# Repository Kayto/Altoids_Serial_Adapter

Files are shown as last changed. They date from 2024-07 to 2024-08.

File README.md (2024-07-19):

# Altoids Serial Adapter

**Latest News**

* **DESIGN IN PROGRESS. UNTESTED**

## Introduction

Fed up with having to use multiple USB serial adapters and wiring configurations? Just want to plug in and go. This project was born from a desire for a quick and neat way to interface with various single board homebrew computers (SBCs)- such as the Kim-Uno, Southern Cross and SC131 to name a few. Most USB serial adapters are bare boards, have tiny pin labels and come with different logic voltages and pin out orders. This makes it a fiddle to set up. What power, what logic, mess around switching dupont jumper cables between the correct pins....
With the Altoid Serial Adapter the fiddle is over. You're welcome!

## Credits and thanks

Credits and thanks are worthy of being up front.

* **Lee Hart** for inspiring the look and feel of this project. Please check out his site for some amazing SBCs. https://www.sunrise-ev.com/index.htm
* Tom Van Baak for the brilliant picDIV™ project. Please check out his site for all things clock.
* bborncr for the initial PCB outline and sizing to fit the Altoids tin. https://github.com/bborncr/AltoidsPCB
* FTDI 

## General Aims

* Provide 'plug and play' connections using fixed ribbon cables for the most typical serial pin connection order. I don't want to be crossing wires and tracing wire colours.
* Provide some nice LEDs.
* Switchable power and serial logic voltages.
* Fit it all to look nice and tidy in an Altoids tin.
* For ease, safety and to simplify both design and assembly (and probably cost) use commercially available modules for the power regulation, multiplexing and charging.
* Limit the SMD to ease assembly.

## Bespoke Aims

These are added features that suit more bespoke applications.

* SBCs such as the Kim-Uno and Membership Cards dont always warrant a serial connection as they can be programmed by switches and buttons. Therefore why not provide some onboard battery power.
* With an onboard battery, may as well be able to charge it.
* As we have regulated power we may as well break it out - to be useful for other things.
* Sometimes you may need a signal High or Low? My use is that some SBCs need a High or Low to activate a display. Provide a switch for that, i like switches.
* Ok, the serial adapter IC has an onboard oscillator. It would be a shame to waste that. Wait, the oscillator runs at 2024 speeds, i need something slower for 1980s tech. Use a PIC to divide the clock and provide a breakout for sub 6MHZ clock signals. Might come in handy.
* For the clock, provide breakouts for onboard PIC programming. This then offers more possibilities without having to disassemble the board.

## Final Features

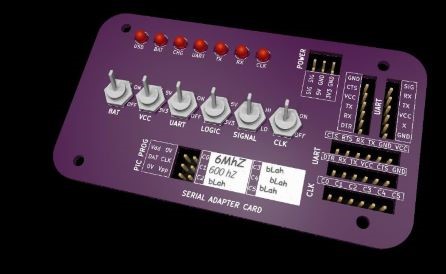
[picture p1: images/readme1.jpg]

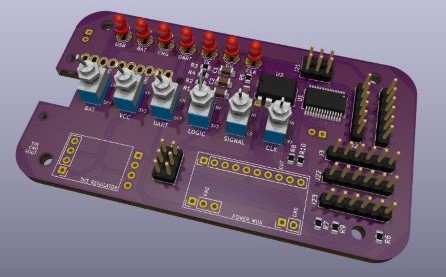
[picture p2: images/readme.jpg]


In no particular order the main features in the final board are as follows.

- Programmable clock breakout using the picDIV™ project.
- Indicator LEDs for the main functions and configurations.
- Onboard Li-ion battery charger.
- Selectable 5V and 3V3 power and logic.
- Seperate Power breakout.
- High and Low signal logic breakout

## Build

Coming Soon.

### REVISION STATUS & ISSUES
**REV 000**
* DRAFT DESIGN IN PRODUCTION. UNTESTED AT THE MOMENT.

## Firmware

Comming soon.
Instructions for the FT232R clock configuration.
Instructions for the picDIV™ project.

## Licenses & acknowledgement
Further to the links in the credit section.

**KiCad Library**

**picDIV™**
http://www.leapsecond.com/pic/
http://www.leapsecond.com/pic/src/readme

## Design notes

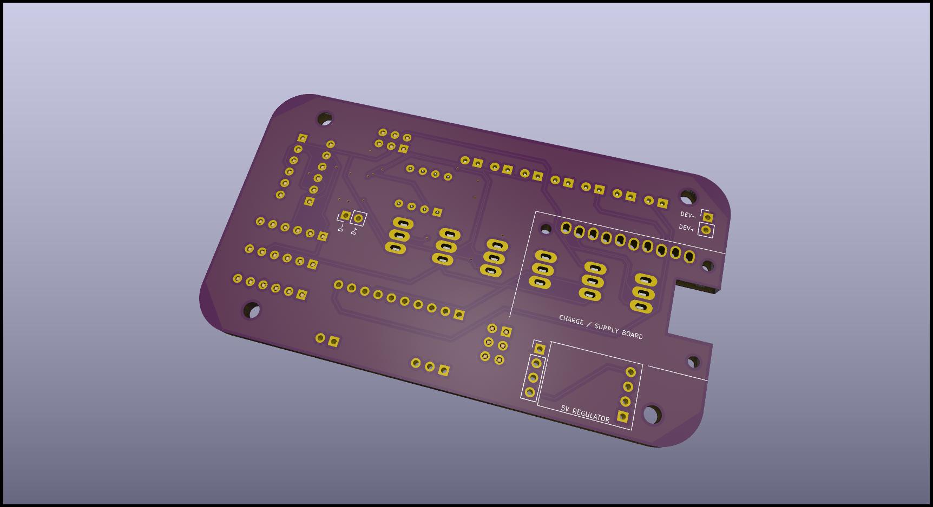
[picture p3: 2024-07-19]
images/Altoids_BOTTOM.jpg

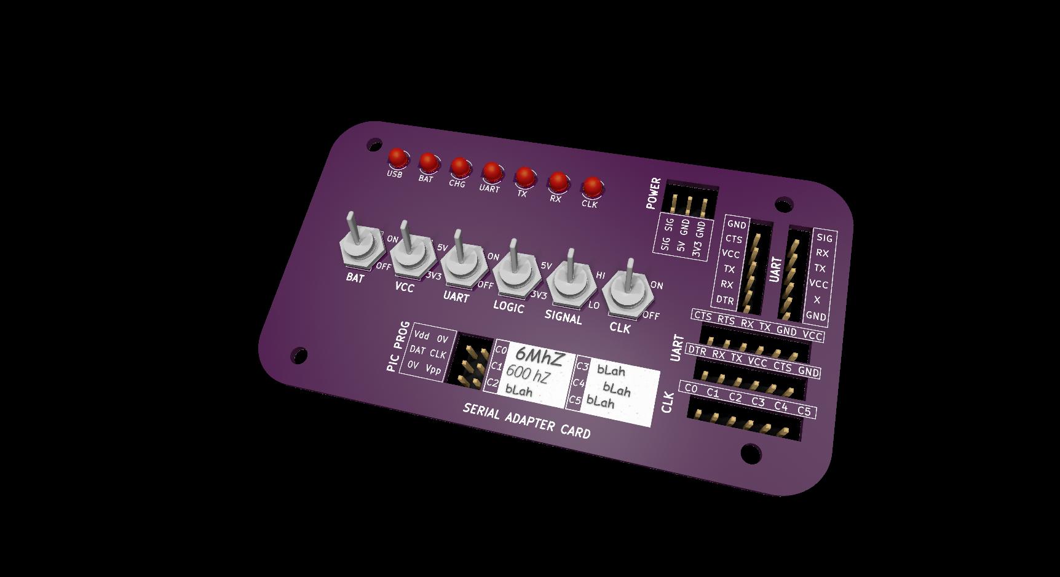
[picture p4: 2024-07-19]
images/Altoids_TOP.jpg

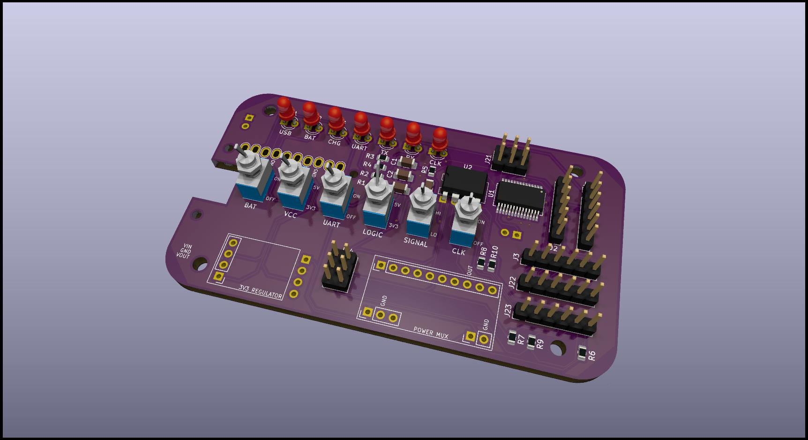
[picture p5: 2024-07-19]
images/Altoids.jpg

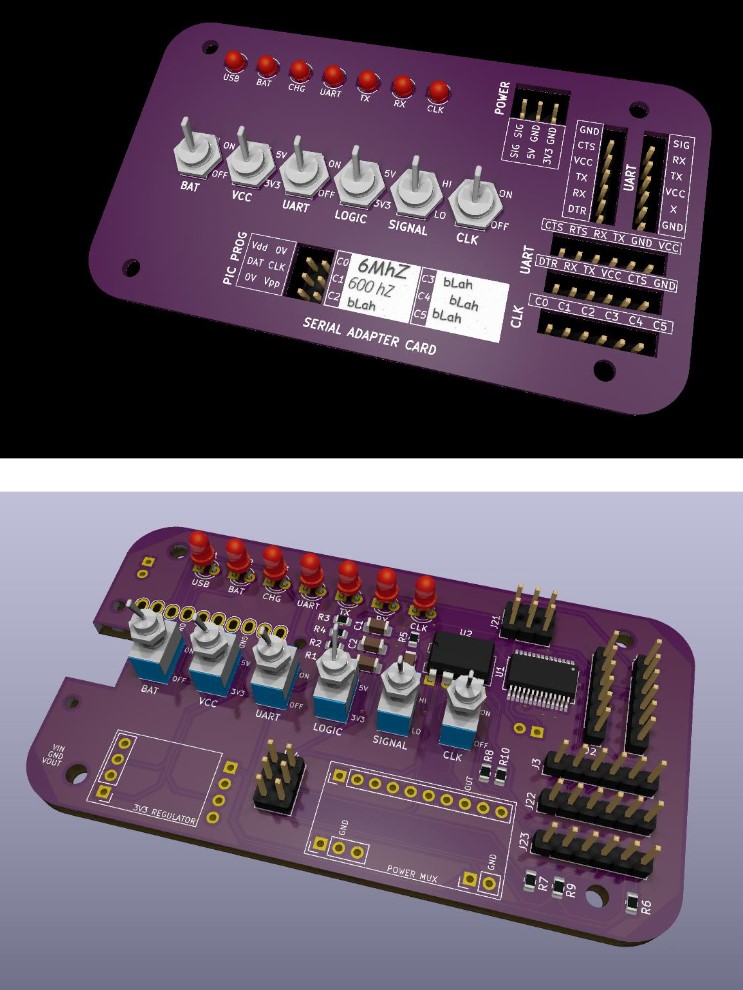
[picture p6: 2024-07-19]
images/readme - Copy.jpg

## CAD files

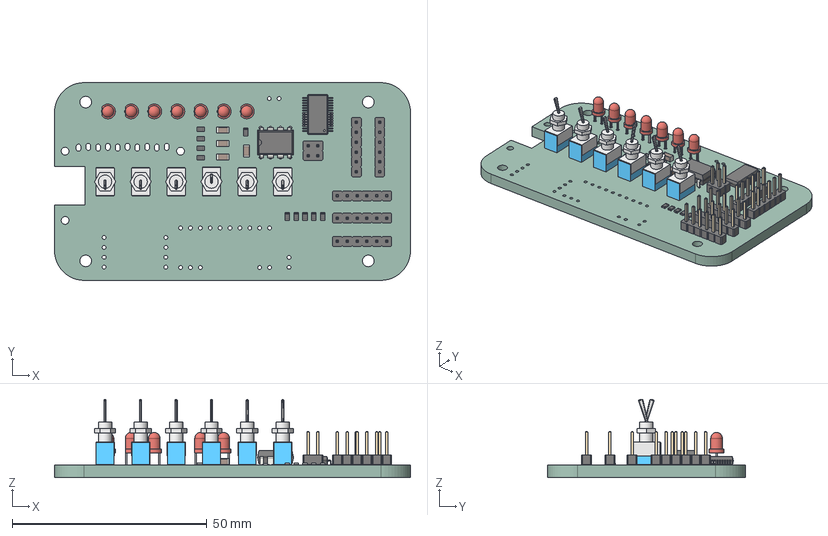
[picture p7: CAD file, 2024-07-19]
KiCAD/Altoids.step
91.4 x 50.8 x 20.1 mm
PinHeader_1x06_P254mm_Vertical x 5
R_0805_2012Metric x 10
C_1206_3216Metric x 4
DIP-8_W7.62mm
LED_D3.0mm x 7
PinHeader_2x02_P254mm_Vertical
SSOP_28_53x102mm_P065mm
_autosave-Altoids_PCB

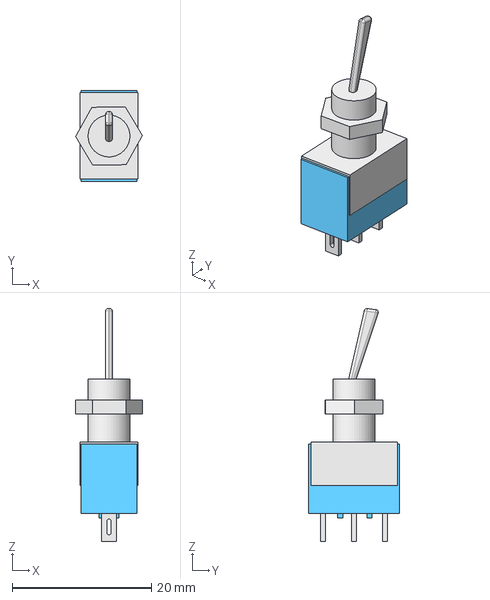
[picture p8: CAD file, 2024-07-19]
KiCAD/Toggle_SW_Blue_R0.step
9.58 x 13.0 x 33.4 mm
Housing
Chrome

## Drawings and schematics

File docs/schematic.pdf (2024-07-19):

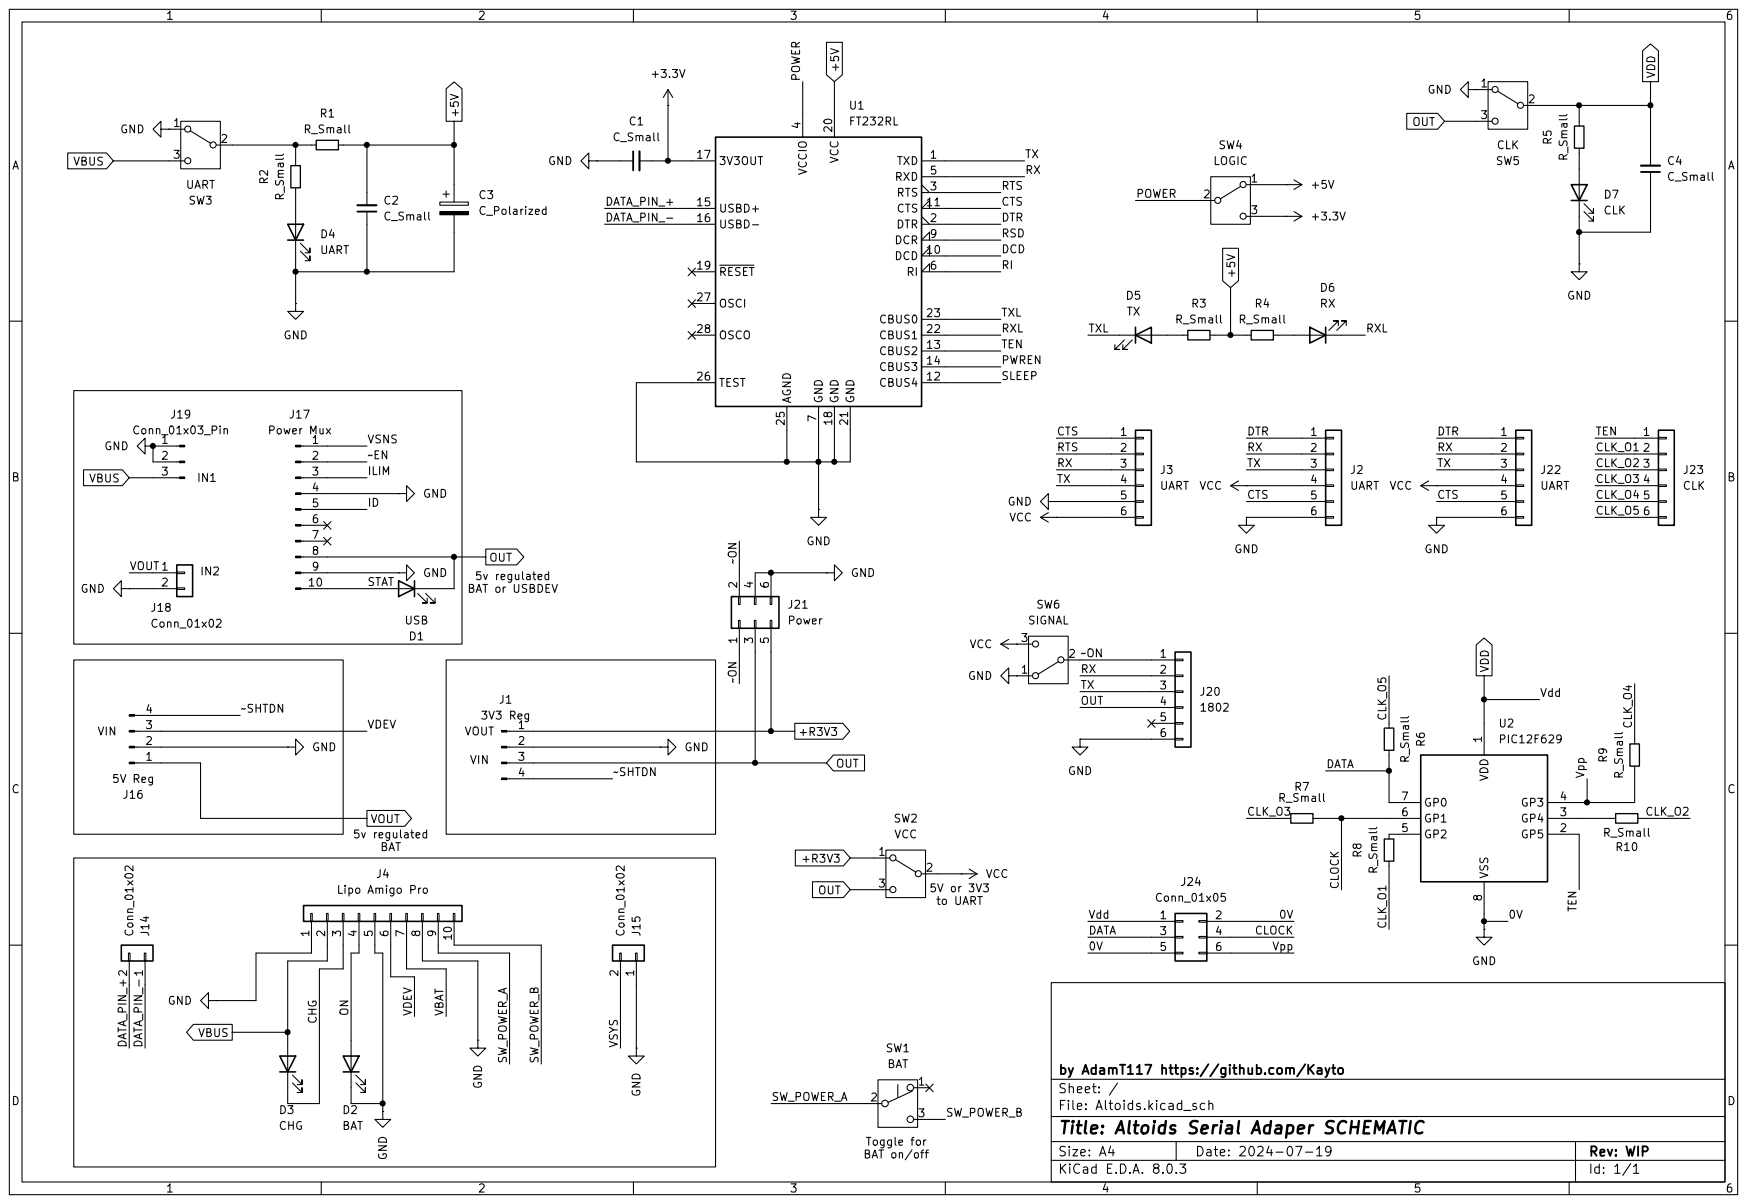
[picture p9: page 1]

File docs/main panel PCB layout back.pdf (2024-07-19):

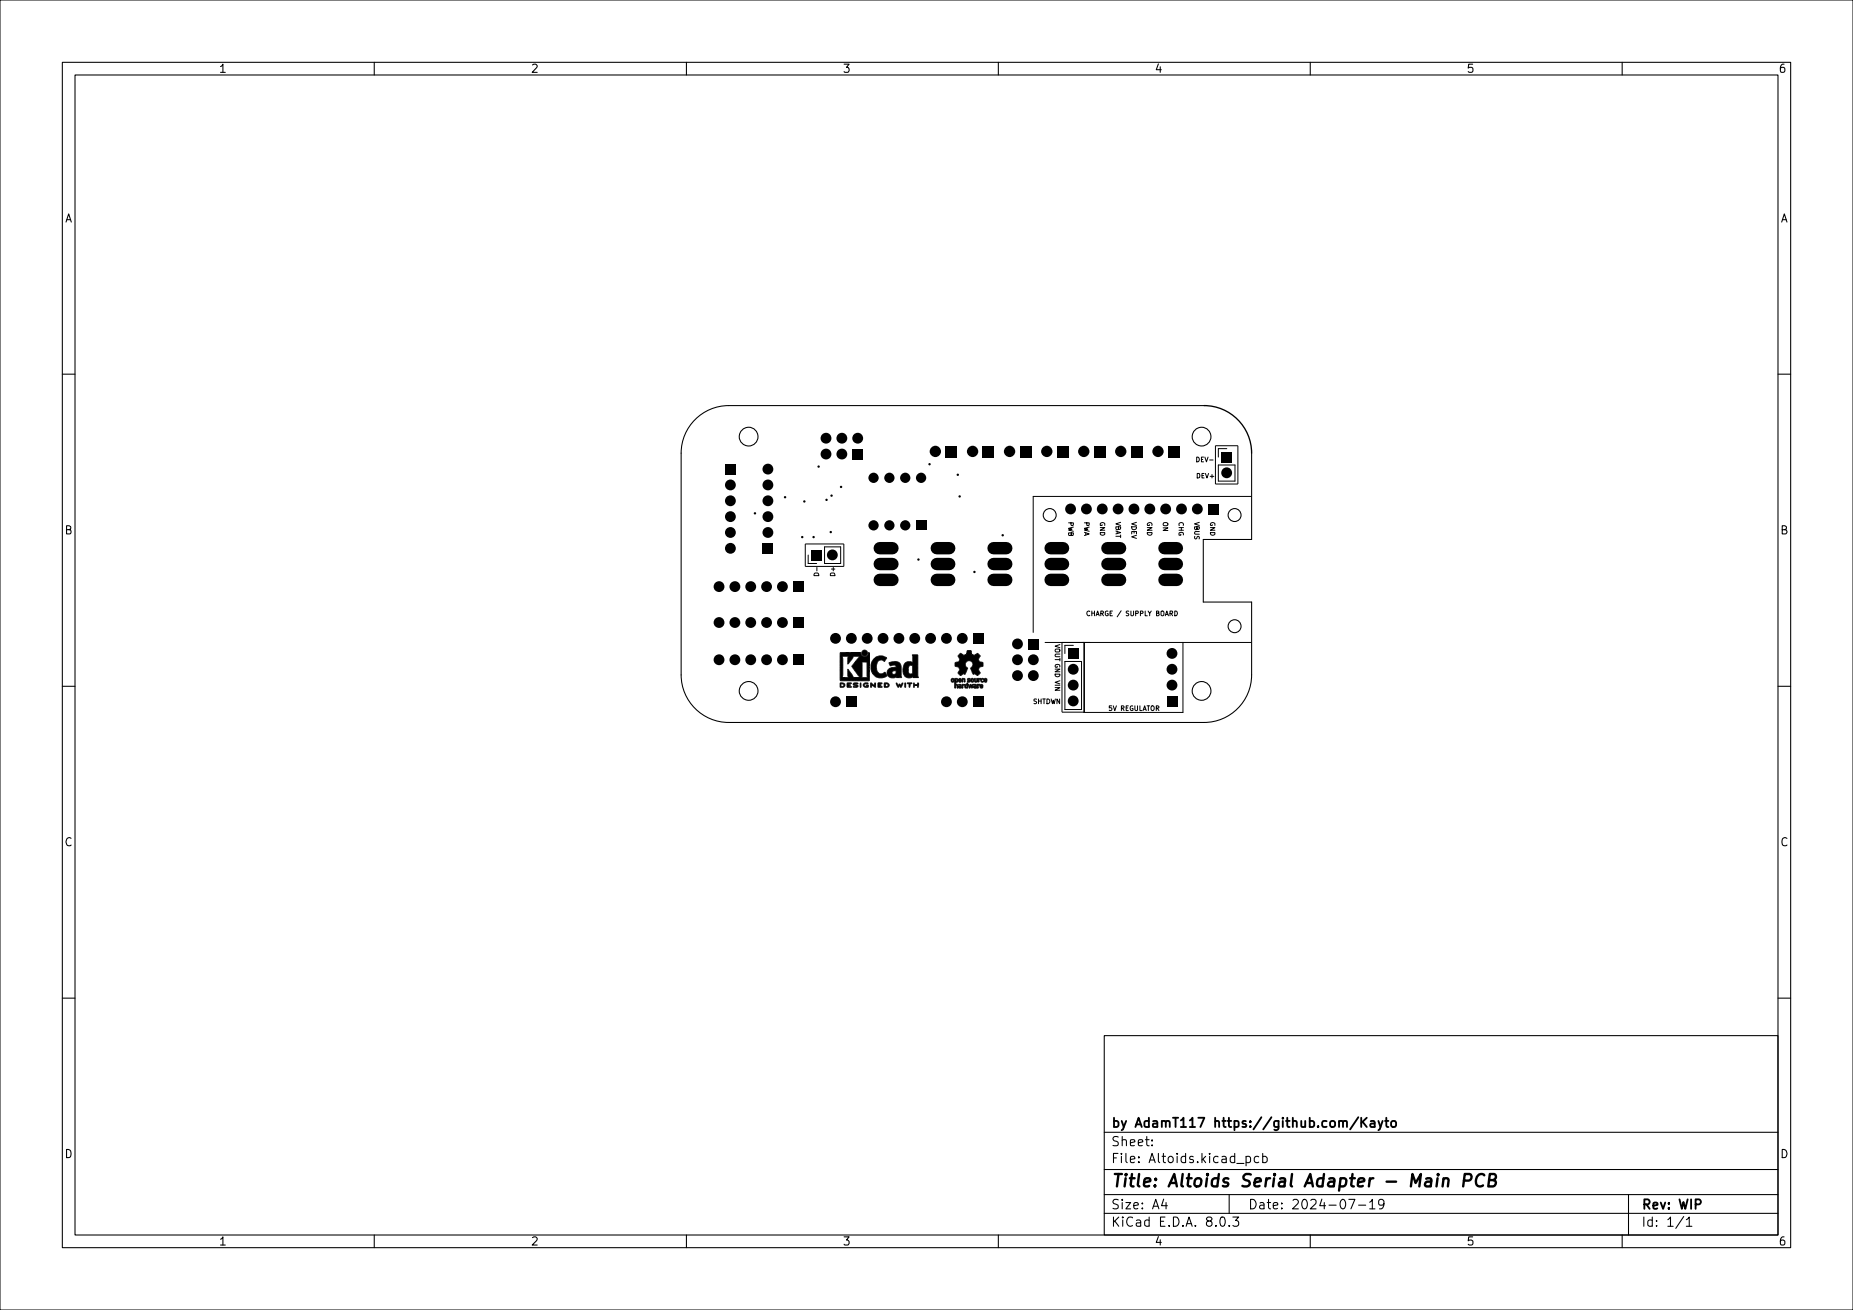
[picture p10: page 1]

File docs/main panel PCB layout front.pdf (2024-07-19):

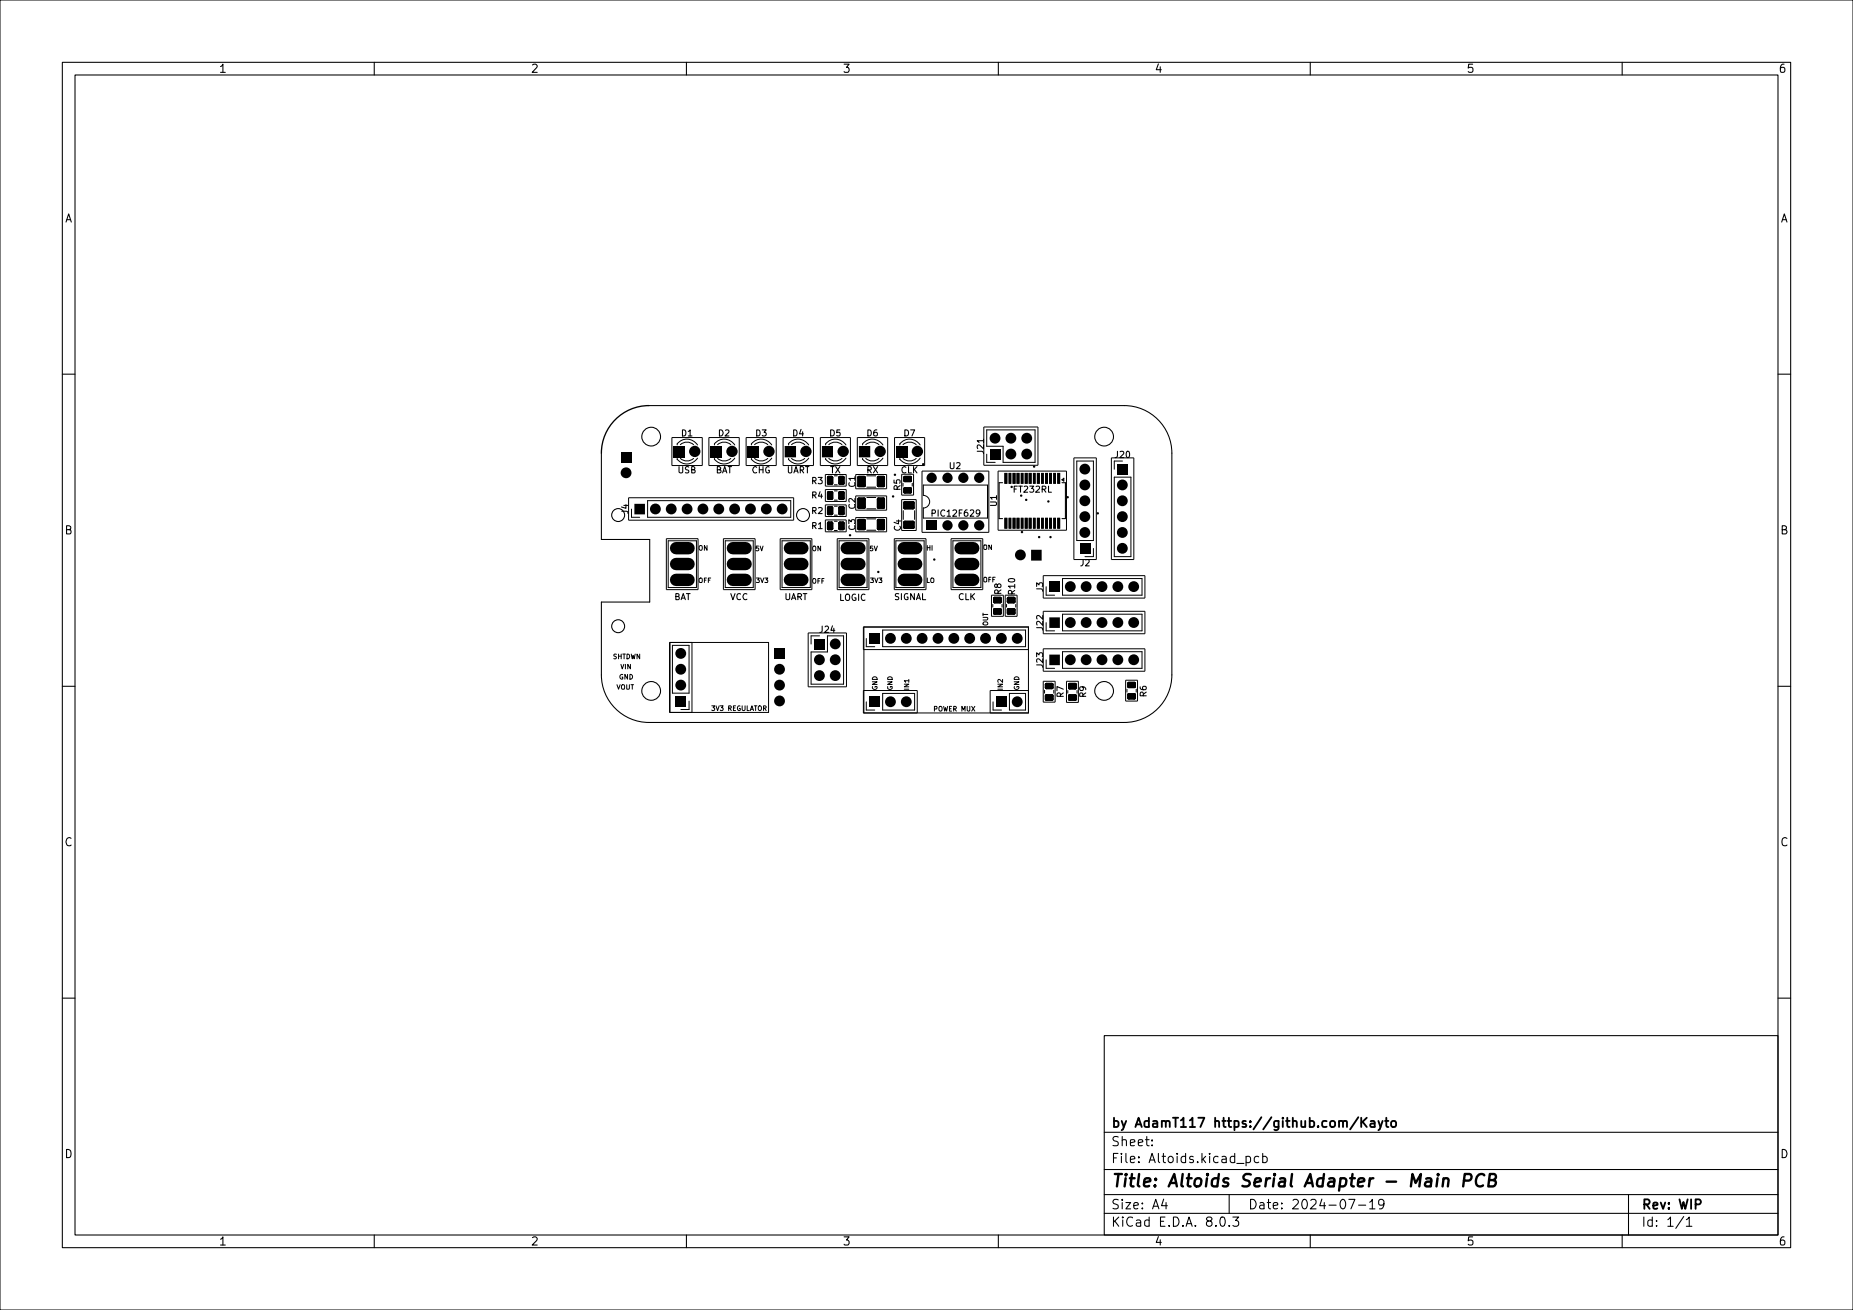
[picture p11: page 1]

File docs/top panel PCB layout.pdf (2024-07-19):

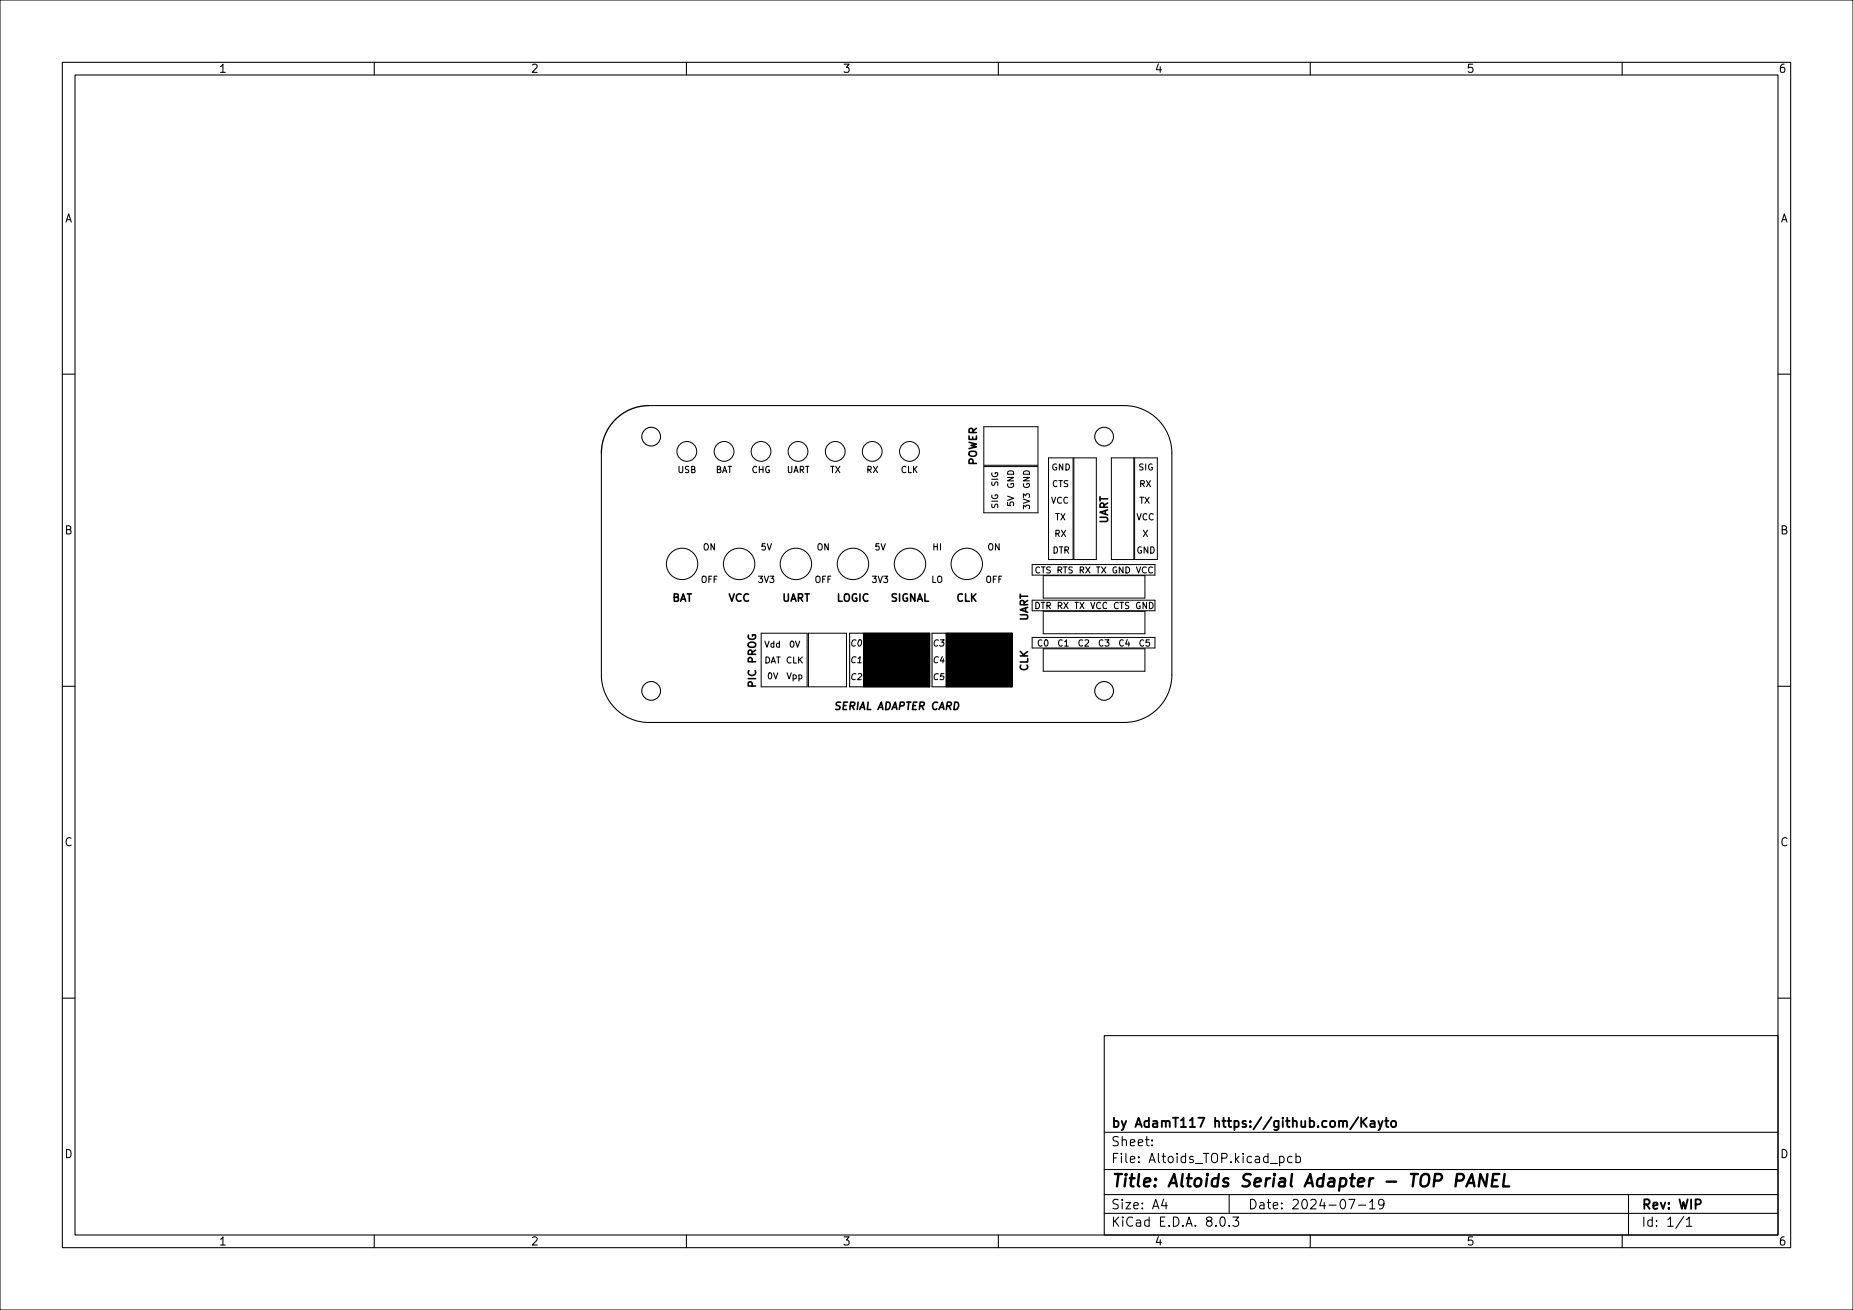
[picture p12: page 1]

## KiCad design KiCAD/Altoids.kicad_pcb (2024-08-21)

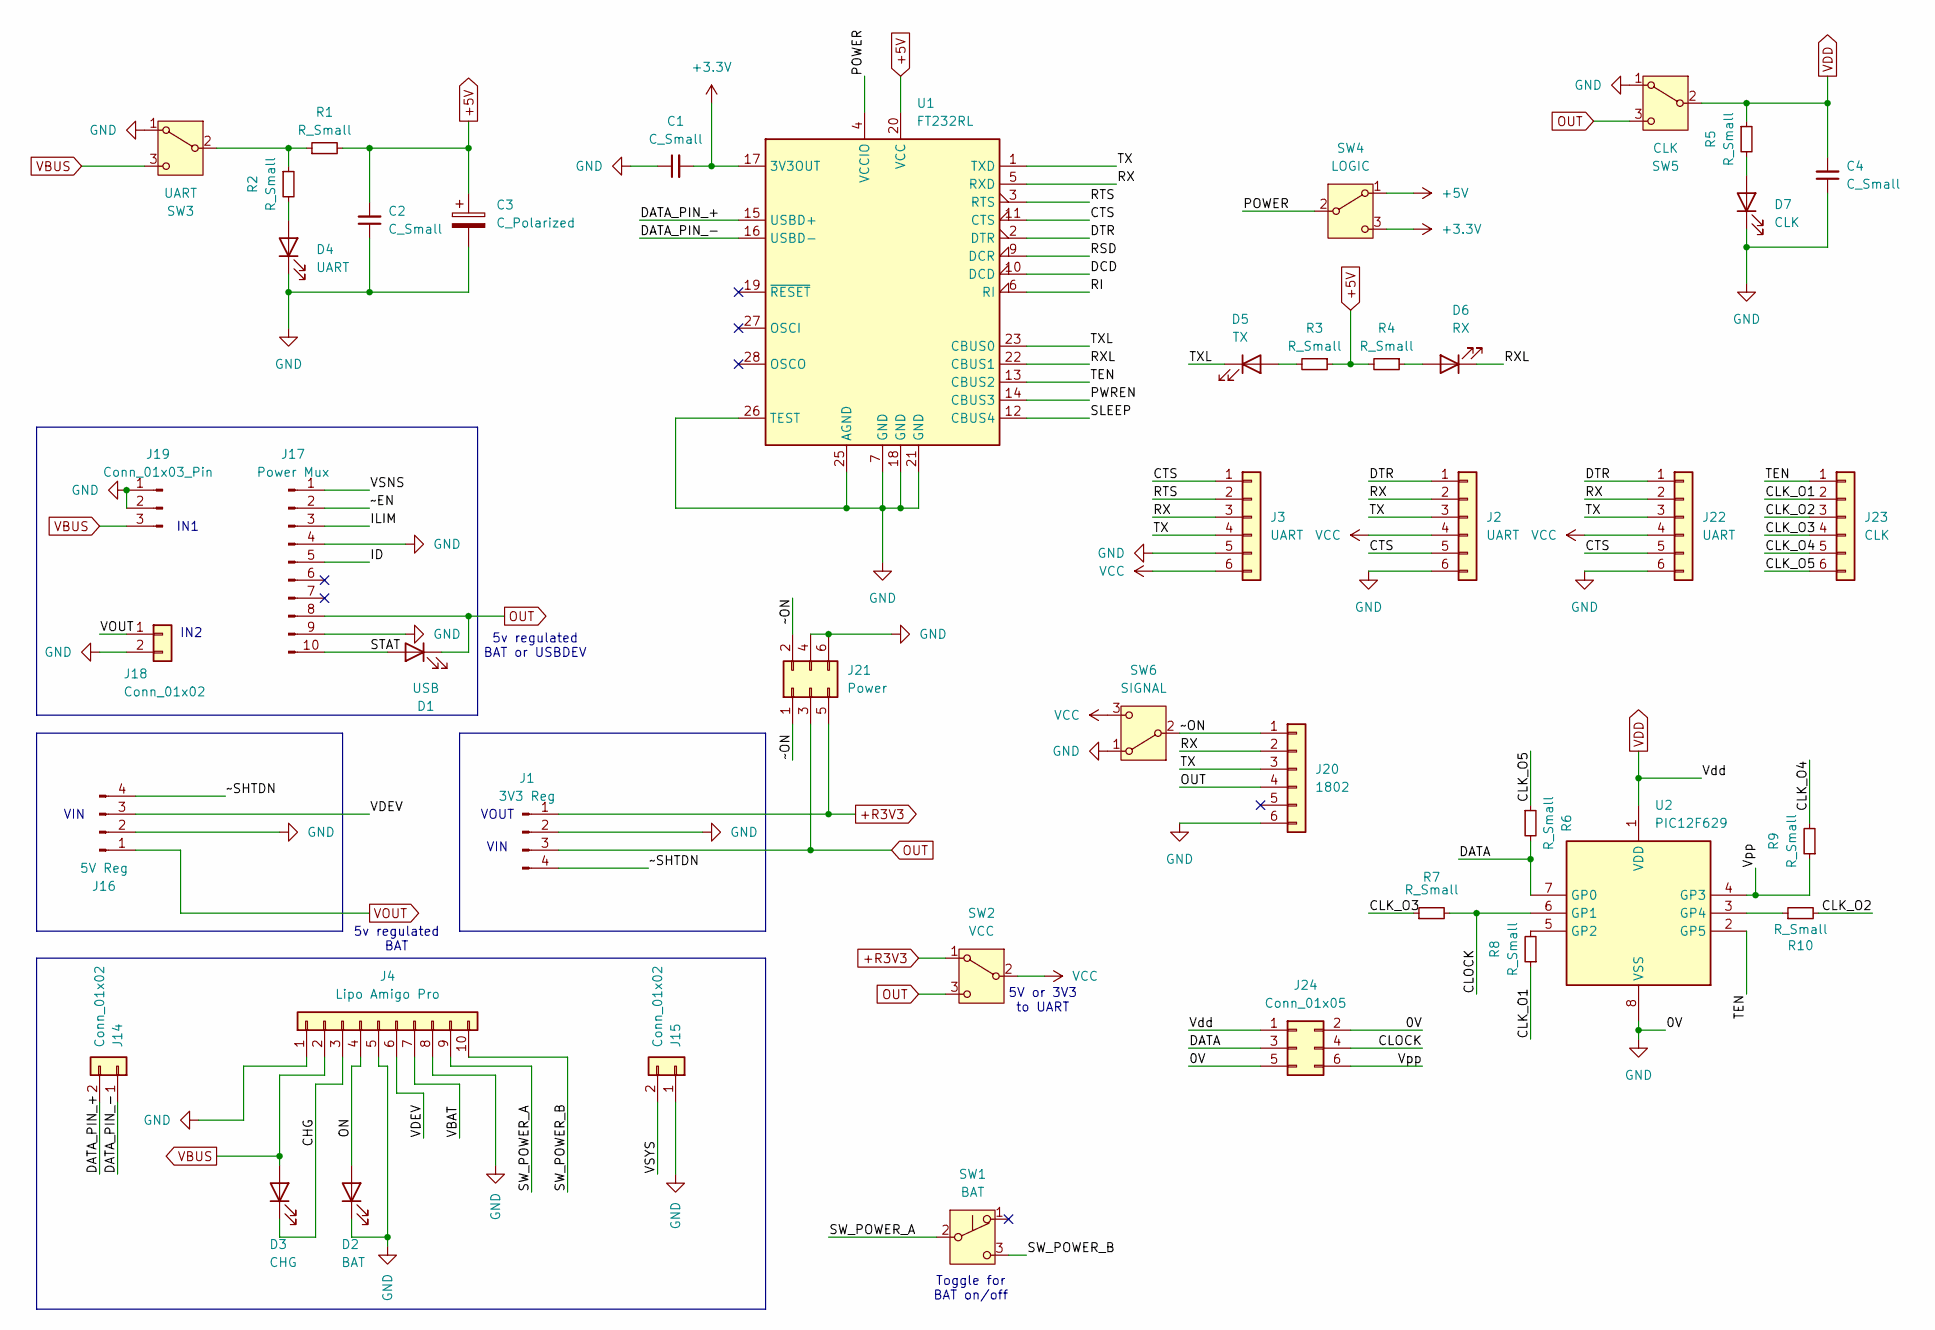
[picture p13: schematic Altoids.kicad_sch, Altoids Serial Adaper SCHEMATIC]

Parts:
C1, C2, C4: C_Small; C_1206_3216Metric_Pad1.33x1.80mm_HandSolder
C3: C_Polarized; C_1206_3216Metric_Pad1.33x1.80mm_HandSolder
D1: USB; LED_D3.0mm
D2: BAT; LED_D3.0mm
D3: CHG; LED_D3.0mm
D4: UART; LED_D3.0mm
D5: TX; LED_D3.0mm
D6: RX; LED_D3.0mm
D7: CLK; LED_D3.0mm
J1: 3V3 Reg; PinHeader_1x04_P2.54mm_Vertical_no_PINS
J2, J3, J22: UART; PinHeader_1x06_P2.54mm_Vertical
J4: Lipo Amigo Pro; PinHeader_1x10_P2.54mm_Vertical
J14, J15, J18: Conn_01x02; PinHeader_1x02_P2.54mm_Vertical_no_PINS
J16: 5V Reg; PinHeader_1x04_P2.54mm_Vertical_no_PINS
J17: Power Mux; PinHeader_1x10_P2.54mm_Vertical_no_PINS
J19: Conn_01x03_Pin; PinHeader_1x03_P2.54mm_Vertical_no_PINS
J20: 1802; PinHeader_1x06_P2.54mm_Vertical
J21: Power; PinHeader_2x03_P2.54mm_Vertical
J23: CLK; PinHeader_1x06_P2.54mm_Vertical
J24: Conn_01x05; PinHeader_2x03_P2.54mm_Vertical
R1, R2, R3, R4, R5, R6, R7, R8, R9, R10: R_Small; R_0805_2012Metric
SW1: BAT; SW_Toggle_Blue_wSlots
SW2: VCC; SW_Toggle_Blue_wSlots
SW3: UART; SW_Toggle_Blue_wSlots
SW4: LOGIC; SW_Toggle_Blue_wSlots
SW5: CLK; SW_Toggle_Blue_wSlots
SW6: SIGNAL; SW_Toggle_Blue_wSlots
U1: FT232RL; SSOP-28_5.3x10.2mm_P0.65mm
U2: PIC12F629; DIP-8_W7.62mm

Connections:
+3.3V: C1.2, SW4.3 (C), U1.17 (3V3OUT)
+5V: C2.2, C3.1, R1.2, R3.1, R4.2, SW4.1 (A), U1.20 (VCC)
+R3V3: J1.1, J21.5, SW2.1 (A)
/CHG: D3.1 (K), J4.3
/CLK_O1: J23.2, R8.1
/CLK_O2: J23.3, R10.2
/CLK_O3: J23.4, R7.1
/CLK_O4: J23.5, R9.2
/CLK_O5: J23.6, R6.1
/CLOCK: J24.4, R7.2, U2.6 (GP1)
/CTS: J2.5, J3.1, J22.5, U1.11 (CTS)
/DATA: J24.3, R6.2, U2.7 (GP0)
/DATA_PIN_+: J14.2, U1.15 (USBD+)
/DATA_PIN_-: J14.1, U1.16 (USBD-)
/DCD: U1.10 (DCD)
/DTR: J2.1, J22.1, U1.2 (DTR)
/ID: J17.5
/ILIM: J17.3
/ON: D2.2 (A), J4.4
/POWER: SW4.2 (B), U1.4 (VCCIO)
/PWREN: U1.14 (CBUS3)
/RI: U1.6 (RI)
/RSD: U1.9 (DCR)
/RTS: J3.2, U1.3 (RTS)
/RX: J2.2, J3.3, J20.2, J22.2, U1.5 (RXD)
/RXL: D6.1 (K), U1.22 (CBUS1)
/SLEEP: U1.12 (CBUS4)
/STAT: D1.2 (A), J17.10
/SW_POWER_A: J4.9, SW1.2 (B)
/SW_POWER_B: J4.10, SW1.3 (C)
/TEN: J23.1, U1.13 (CBUS2), U2.2 (GP5)
/TX: J2.3, J3.4, J20.3, J22.3, U1.1 (TXD)
/TXL: D5.1 (K), U1.23 (CBUS0)
/VBAT: J4.7
/VDEV: J4.6, J16.3
/VSNS: J17.1
/VSYS: J15.2
/Vpp: J24.6, R9.1, U2.4 (GP3)
/~EN: J17.2
/~ON: J20.1, J21.1, J21.2, SW6.2 (B)
/~SHTDN: J1.4, J16.4
GND: C1.1, C2.1, C3.2, C4.1, D2.1 (K), D4.1 (K), D7.1 (K), J1.2, J2.6, J3.5, J4.1, J4.5, J4.8, J15.1, J16.2, J17.4, J17.9, J18.2, J19.1, J19.2, J20.6, J21.4, J21.6, J22.6, J24.2, J24.5, SW3.1 (A), SW5.1 (A), SW6.1 (A), U1.7 (GND), U1.18 (GND), U1.21 (GND), U1.25 (AGND), U1.26 (TEST), U2.8 (VSS)
unnamed: D4.2 (A), R2.2
unnamed: D5.2 (A), R3.2
unnamed: D6.2 (A), R4.1
unnamed: D7.2 (A), R5.2
unnamed: R1.1, R2.1, SW3.2 (B)
unnamed: R8.2, U2.5 (GP2)
unnamed: R10.1, U2.3 (GP4)
OUT: D1.1 (K), J1.3, J17.8, J20.4, J21.3, SW2.3 (C), SW5.3 (C)
VBUS: D3.2 (A), J4.2, J19.3, SW3.3 (C)
VCC: J2.4, J3.6, J22.4, SW2.2 (B), SW6.3 (C)
VDD: C4.2, J24.1, R5.1, SW5.2 (B), U2.1 (VDD)
VOUT: J16.1, J18.1

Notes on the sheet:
VOUT
Toggle for BAT on/off
5V or 3V3 to UART
5v regulated BAT
VIN
IN1
5v regulated BAT or USBDEV
IN2

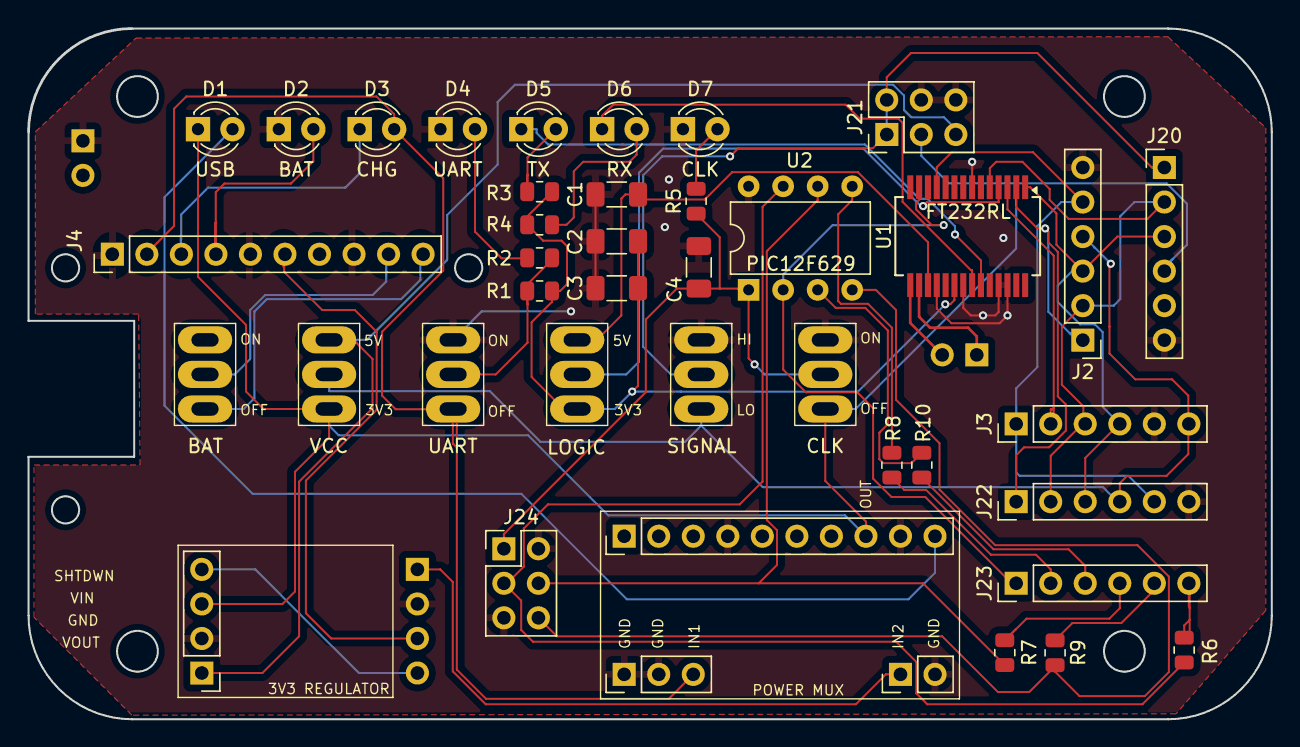
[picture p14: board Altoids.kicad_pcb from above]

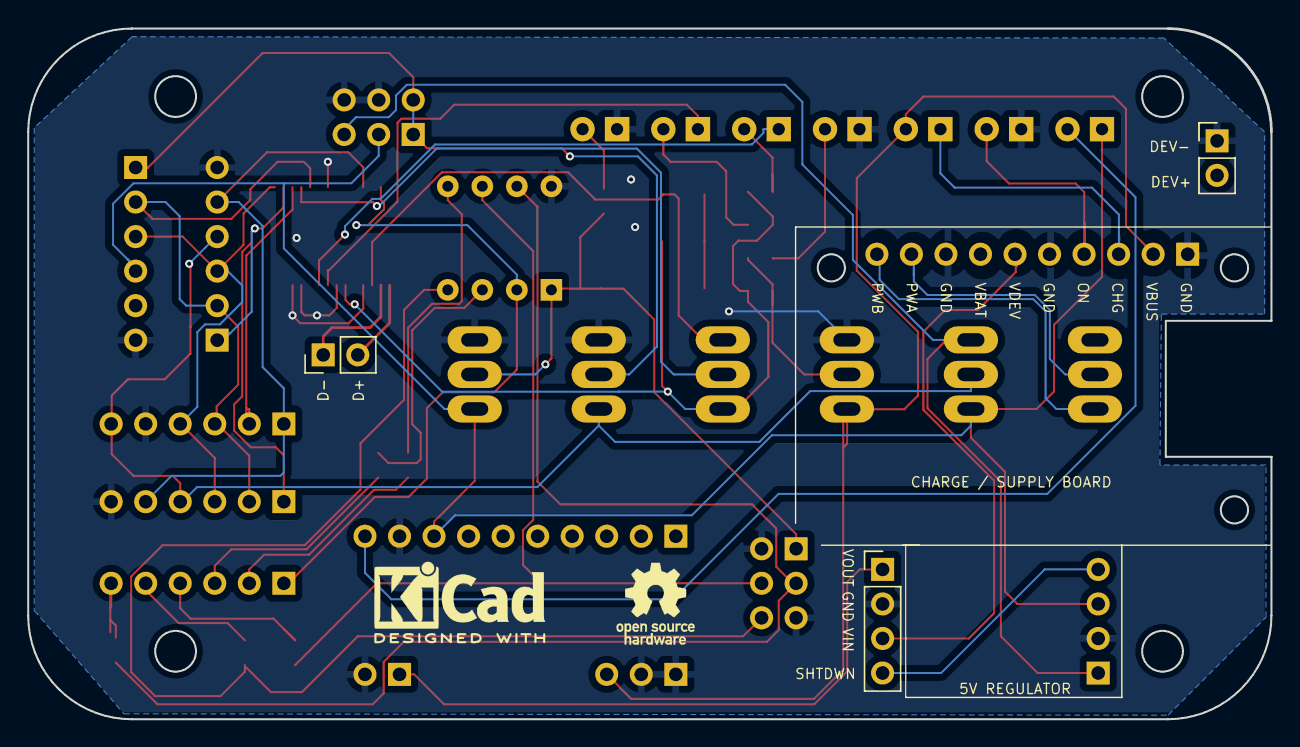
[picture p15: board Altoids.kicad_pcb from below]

Board: 2 copper layers, 91.4 x 50.8 mm, 44 parts (3 on the bottom side), 43 nets.
